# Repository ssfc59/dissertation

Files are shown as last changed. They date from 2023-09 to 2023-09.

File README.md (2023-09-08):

# Warm Reminders in Cool Spaces: Real-time monitoring of the thermal environment in Stratford Library with an integrated sensing and display device

## Overview





This "Warm Reminder" is a device that both senses and shows the real-time comparative temperature and humidity inside Stratford Library, a designated Tier 1 Cool Space by the Greater London Authority, and the surrounding area. It also sends the exact values recorded by the device over time to a data visualisation platform.

 As part of a collaboration with Newham Council and Stratford Library staff, this device was deployed in the library to inform both library staff and visitors of the facility's cooling efficacy and investigate its adherence to the 2023 Cool space criteria of having a "cooler indoor temperature than outdoors" during hot weather.

It aimed to engage both the public and the government on the emerging problem of heat, which could enourage heat adapation measures on both an individual and urban management level to increase community climate resilience to the adverse effects of extreme heat exposure.

To see the exact values recorded by this device, [click here](https://go.init.st/6woxrdn) or scan the QR code, and [click here to view the GLA Cool Spaces Map.](https://apps.london.gov.uk/cool-spaces/)

## Research Question
Can deploying a real-time integrated temperature and humidity sensing and display device inside Stratford Library help to indicate its cooling efficacy as a cool space over time?

## Device Function
The device takes the form of a large book-shaped light-up textual display that shows a comparative sentence of Stratford Library’s temperature and humidity values compared to outside on its “book cover”. 

It is run by a **FireBeetle ESP32 IOT Microcontroller**, which controls a **WS2812B LED strip** on the inside and a **DHT22 temperature and humidity sensor** on its side. 

Every 3 minutes from 9am-8pm, Stratford Library’s opening hours, the device collects and compares temperature, humidity, and heat index readings from the DHT22 sensor and the Met Office’s Weather DataHub, lights up the corresponding values and modifiers on the display, then sends the collected values to Initial State, a data visualisation platform that visualises the exact values of each variable over time on multiple charts.

## Device Fabrication
My device incorporates the visual features of a book, including its shape, material, proportion, and textual display format in its design as a reference to its placement in Stratford Library.

I used boxes.py, Fusion360, and Adobe Illustrator to make a laser cut template of a book shaped box with a curved side, with cut out stencilled text of the value displays onto its front, and cut it out of black acrylic. 




I then attached the LED strip to the back of each display row.



Lastly, I designed and laser cut a paper overlay with permanent parts of the sentence display and placed it on the device's front face to conceal the cutouts, only allowing the LED-lit values and descriptors to be visible.




I also laser cut 2 vertically lined pieces of white paper and placed them on the sides, making it resemble the pages of a book between book covers.



When the device is working, the display shows a sentence that compares the real-time temperature and humidity values inside Stratford Library to that outside. 



## Code Components
After connecting to WiFi successfully, my device’s code comprises 6 main chunks:

1.	Obtain the current hour and run the rest of the code if it is between 9am-8pm.

2.	Make a secured Get request to the Weather DataHub API to obtain the temperature, humidity, and “feels like” temperature of the area around Stratford Library.

3.	Obtain temperature, humidity, and heat index readings from the DHT22 sensor.

4.	Subtract the API values from the sensor values to find the temperature and humidity difference between Stratford Library and the surrounding outdoor area.

5.	Light up the LED lights to illuminate the corresponding numerical values and text descriptions on the display.

6.	Post all the received values to Initial State.

7.	2-minute delay between iterations.

### Arduino Libraries:

- [EzTime Library](https://github.com/ropg/ezTime) was used to obtain the current hour in a simple way.
- [ArduinoJson](https://arduinojson.org/) was used to deserialise the API response from Met Office DataHub.
- [WiFiClientSecure](https://github.com/espressif/arduino-esp32/blob/master/libraries/WiFiClientSecure/README.md) was used to make secure GET and POST requests.
- [FastLED](https://github.com/FastLED/FastLED) was used to control the LED lights.

## Repository contents
- Code
- Laser cut templates
- 3D printed ESP32 enclosure
- Data collected

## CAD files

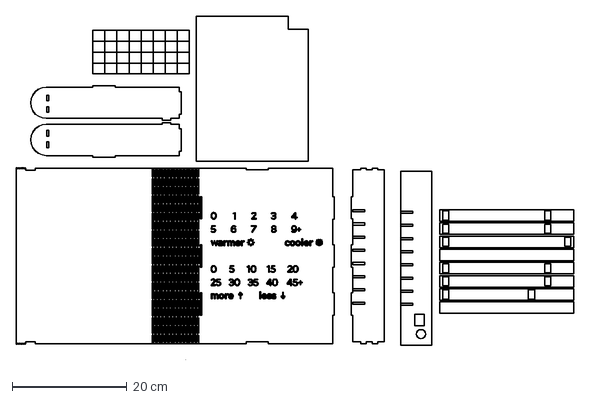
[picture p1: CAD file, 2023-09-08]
device-acrylic-laser-cut.dxf
97.3 x 60.0 cm

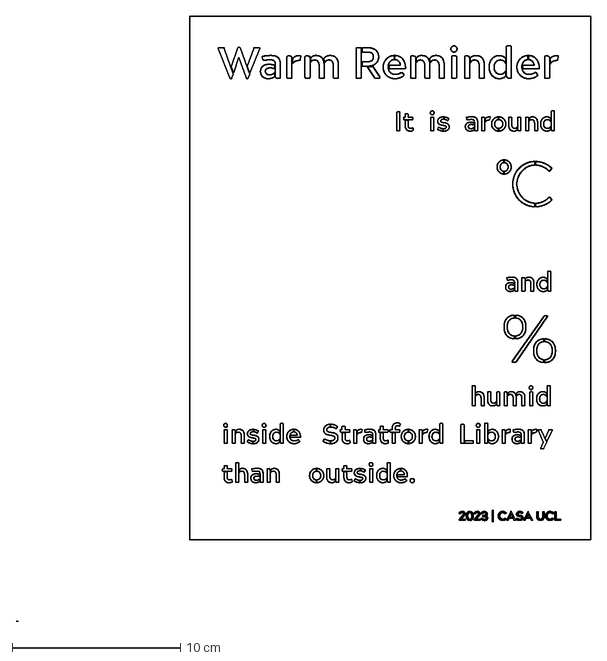
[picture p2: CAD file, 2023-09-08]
laser cut templates/device-front-paper-overlay.dxf
34.1 x 35.9 cm

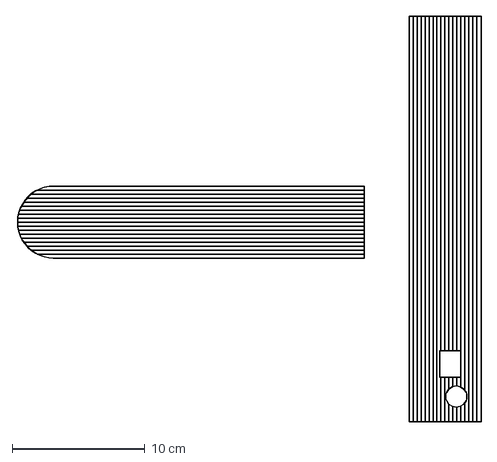
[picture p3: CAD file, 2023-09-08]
laser cut templates/device-sides-paper-overlay.dxf
35.1 x 30.6 cm

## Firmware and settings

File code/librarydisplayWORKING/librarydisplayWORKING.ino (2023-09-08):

#include <ArduinoJson.h>
#include <Arduino.h>
#include <WiFi.h>
#include <WiFiClientSecure.h>
#include <HTTPClient.h>

//ezTime library
#include <ezTime.h>
Timezone myTimezone;
int startHour = 8;    // Start hour (24-hour format)
int endHour = 20;

// LEDS
#include <FastLED.h>
#define NUM_LEDS 192     //Number of RGB LED beads
#define DATA_PIN D8    //The pin for controlling RGB LED
#define LED_TYPE WS2812B    //RGB LED strip type
CRGB leds[NUM_LEDS];    //Instantiate RGB LED

// DHT
#include "DHT.h"
#define DHTPIN D3    // Digital pin connected to the DHT sensor
#define DHTTYPE DHT22
DHT dht(DHTPIN, DHTTYPE);

//WiFi
int counter = 0;

#include "arduino_secrets.h";

void setup()
{
  // init serial
  Serial.begin(115200);

  //init LEDs
  FastLED.addLeds<LED_TYPE, DATA_PIN>(leds, NUM_LEDS);
  Serial.println();
  FastLED.clear();

  //init DHT
  dht.begin();
  Serial.println("wake device up for 5 seconds");
  delay(5000);

  //init WiFi
  WiFi.mode(WIFI_STA);
  WiFi.begin(ssid, password);
  Serial.print("Connecting to WiFi ..");
  while (WiFi.status() != WL_CONNECTED) {
    Serial.print('.');
//shows 1C cooler and 10% more humid
    for (int i = 183; i <= 186; i++) {
      leds[i] = CRGB (255, 255, 255);
      FastLED.show();
    }

    for (int i = 92; i <= 102; i++) {
      leds[i] = CRGB (255, 255, 255);
      FastLED.show();
    }

    //1 cooler
    //10 more

    for (int i = 1; i <= 10; i++) {
      leds[i] = CRGB (255, 255, 255);
      FastLED.show();
    }

    for (int i = 70; i <= 72; i++) {
      leds[i] = CRGB (255, 255, 255);
      FastLED.show();
    }

    counter++;
    delay(1000);
    if (counter >= 300) { //60 seconds timeout - reset board
      Serial.print(F("failed to connect after 60 seconds, reset board"));
      ESP.restart();
    }
  }
  FastLED.clear();
  counter = 0; //reset counter
  Serial.println(WiFi.localIP());
  waitForSync();
  myTimezone.setPosix("GMT0BST,M3.5.0/1,M10.5.0"); //set timezone to GMT
}

void loop () {
  /////////////////////
  // 1. Get the time //
  /////////////////////

  int currentHour = myTimezone.hour();
  Serial.println("Current Hour is ");
  Serial.print(currentHour);
  Serial.println(":00");

  /////////////////////////////////
  // 2. Make secured Get Request //
  /////////////////////////////////


  if (currentHour >= startHour && currentHour < endHour) {
    WiFiClientSecure *client = new WiFiClientSecure;
    // set secure client without certificate
    client->setInsecure();
    //create an HTTPClient instance
    HTTPClient https;
    https.begin(*client, APIurl);
    Serial.print("[HTTPS] GET...\n");
    https.addHeader("X-IBM-Client-Id", clientId);
    https.addHeader("X-IBM-Client-Secret", clientSecret);
    https.setTimeout(5000);
    int httpCode = https.GET();

    if (httpCode <= 0) {
      Serial.printf("[HTTPS] GET... failed, error: %s\n", https.errorToString(httpCode).c_str());
      Serial.println(F("Error on API request"));
      Serial.print(F("Restarting in 5 seconds..."));
      delay(5000);
      ESP.restart(); //restart ESP32
    }


    else {
      String payload = https.getString();

      //Parse response
      DynamicJsonDocument doc(49152);
      DeserializationError error = deserializeJson(doc, payload);

      // Test if parsing succeeds
      if (error) {
        Serial.print(F("deserializeJson() failed: "));
        Serial.println(error.f_str());
        return;
      }

      //fetch and store values
      float Temperature = doc["features"][0]["properties"]["timeSeries"][2]["screenTemperature"];
      float Humidity = doc["features"][0]["properties"]["timeSeries"][2]["screenRelativeHumidity"];
      float HeatIndex = doc["features"][0]["properties"]["timeSeries"][2]["feelsLikeTemperature"];

      //print values
      Serial.print(F("Outside temperature: "));
      Serial.print(Temperature);
      Serial.print(F(" | Outside humidity: "));
      Serial.print(Humidity);
      Serial.print(F(" | Ambient temperature: "));
      Serial.print(HeatIndex);
      Serial.println();

      //////////////////////////
      // 3. Obtain DHT values //
      //////////////////////////

      // Reading temperature, humidity and heat index
      float t = dht.readTemperature();
      float h = dht.readHumidity();
      float hic = dht.computeHeatIndex(t, h, false);
      //heat index = what the temperature feels like to the human body when relative humidity is combined with the air temperature.
      //false so it returns values in degrees Celsius

      // Check if any reads failed and exit early (to try again).
      if (isnan(h) || isnan(t) || isnan(hic)) {
        Serial.println(F("Failed to read from DHT sensor!"));
        Serial.println(F("2 minutes to debug..."));
        delay(120000);
        return;
      }

      Serial.print(F("Temperature: "));
      Serial.print(t);
      Serial.print(F("°C |"));
      Serial.print(F("Humidity: "));
      Serial.print(h);
      Serial.print(F("% |"));
      Serial.print(F(" Heat index: "));
      Serial.print(hic);
      Serial.print(F("°C "));
      Serial.println();

      //////////////////////////////////////
      // 4. Compare sensor and API values //
      //////////////////////////////////////

      int tempdisplay = t - Temperature;
      Serial.print(F("tempdisplay = "));
      Serial.print(tempdisplay);
      Serial.print(F("°C"));
      Serial.println();

      int humiditydisplay = h - Humidity;
      Serial.print(F("humiditydisplay = "));
      Serial.print(humiditydisplay);
      Serial.print(F("°C"));
      Serial.println();

      ////////////////////////////////////////////
      //  5. Light up corresponding LED lights  //
      ////////////////////////////////////////////

      FastLED.clear();
      if (tempdisplay <= 0) {
        //COOLER INSIDE THE LIBRARY
        for (int i = 92; i <= 102; i++) {
          leds[i] = CRGB (255, 255, 255);
          FastLED.show();
        }
      }
      else if (tempdisplay > 0) {
        //WARMER INSIDE THE LIBRARY
        for (int i = 109; i <= 120; i++) {
          leds[i] = CRGB (255, 255, 255);
          FastLED.show();
        }
      }
      switch (tempdisplay) {
        case 0:
          for (int i = 188; i <= 192; i++) {
            leds[i] = CRGB (255, 255, 255);
            FastLED.show();
          }
          break; //end case, light up 0

        case -1:
        case 1:
          for (int i = 183; i <= 186; i++) {
            leds[i] = CRGB (255, 255, 255);
            FastLED.show();
          }
          break; //end case, light up 1

        case -2:
        case 2:
          for (int i = 179; i <= 181; i++) {
            leds[i] = CRGB (255, 255, 255);
            FastLED.show();
          }
          break; //end case, light up 2

        case -3:
        case 3:
          for (int i = 174; i <= 176; i++) {
            leds[i] = CRGB (255, 255, 255);
            FastLED.show();
          }
          break; //end case, light up 3

        case -4:
        case 4:
          for (int i = 169; i <= 170; i++) {
            leds[i] = CRGB (255, 255, 255);
            FastLED.show();
          }
          break; //end case, light up 4

        case -5:
        case 5:
          for (int i = 128; i <= 132; i++) {
            leds[i] = CRGB (255, 255, 255);
            FastLED.show();
          }
          break; //end case, light up 5

        case -6:
        case 6:
          for (int i = 133; i <= 135; i++) {
            leds[i] = CRGB (255, 255, 255);
            FastLED.show();
          }
          break; //end case, light up 6

        case -7:
        case 7:
          for (int i = 138; i <= 140; i++) {
            leds[i] = CRGB (255, 255, 255);
            FastLED.show();
          }
          break; //end case, light up 7

        case -8:
        case 8:
          for (int i = 143; i <= 145; i++) {
            leds[i] = CRGB (255, 255, 255);
            FastLED.show();
          }
          break; //end case, light up 8

        case -50 ... -9:
        case 9 ... 50:
          for (int i = 148; i <= 151; i++) {
            leds[i] = CRGB (255, 255, 255);
            FastLED.show();
          }
          break; //end case, light up 9+

        default:
          for (int i = 0; i < NUM_LEDS; i++) {
            leds[i] = CRGB(100, 100, 0); //yellow
            FastLED.show();
          }
          Serial.print("Sensor error");
      }

      if (humiditydisplay <= 0) {
        //LESS HUMID
        for (int i = 13; i <= 19; i++) {
          leds[i] = CRGB (255, 255, 255);
          FastLED.show();
        }
      }
      else if (humiditydisplay > 0) {
        //MORE HUMID
        for (int i = 1; i <= 10; i++) {
          leds[i] = CRGB (255, 255, 255);
          FastLED.show();
        }
      }

      switch (humiditydisplay) {
        case -4 ... -1:
        case 0:
        case 1 ... 4:
          for (int i = 60; i <= 63; i++) {
            leds[i] = CRGB (255, 255, 255);
            FastLED.show();
          }
          break; //end case, light up 0

        case -9 ...-5:
        case 5 ... 9:
          for (int i = 65; i <= 67; i++) {
            leds[i] = CRGB (255, 255, 255);
            FastLED.show();
          }
          break; //end case, light up 5

        case -14 ...-10:
        case 10 ... 14:
          for (int i = 70; i <= 72; i++) {
            leds[i] = CRGB (255, 255, 255);
            FastLED.show();
          }
          break; //end case, light up 10

        case -19 ...-15:
        case 15 ... 19:
          for (int i = 75; i <= 77; i++) {
            leds[i] = CRGB (255, 255, 255);
            FastLED.show();
          }
          break; //end case, light up 15

        case -24 ...-20:
        case 20 ... 24:
          for (int i = 80; i <= 83; i++) {
            leds[i] = CRGB (255, 255, 255);
            FastLED.show();
          }
          break; //end case, light up 20

        case -29 ... -25:
        case 25 ... 29:
          for (int i = 52; i <= 54; i++) {
            leds[i] = CRGB (255, 255, 255);
            FastLED.show();
          }
          break; //end case, light up 25

        case -34 ... -30:
        case 30 ... 34:
          for (int i = 47; i <= 49; i++) {
            leds[i] = CRGB (255, 255, 255);
            FastLED.show();
          }
          break; //end case, light up 30

        case -39 ... -35:
        case 35 ... 39:
          for (int i = 42; i <= 45; i++) {
            leds[i] = CRGB (255, 255, 255);
            FastLED.show();
          }
          break; //end case, light up 35

        case -44 ... -40:
        case 40 ... 44:
          for (int i = 38; i <= 40; i++) {
            leds[i] = CRGB (255, 255, 255);
            FastLED.show();
          }
          break; //end case, light up 40

        case -100 ... -45:
        case 45 ... 100:
          for (int i = 30; i <= 35; i++) {
            leds[i] = CRGB (255, 255, 255);
            FastLED.show();
          }
          break; //end case, light up 45+

        default:
          for (int i = 0; i < NUM_LEDS; i++) {
            leds[i] = CRGB(100, 100, 0); //yellow
            FastLED.show();
          }
          Serial.print("Sensor error");
      } //switch humiditydisplay

      //////////////////////////////////////////
      //  6. send all values to Initial State //
      //////////////////////////////////////////

      String url = "https://groker.init.st/api/events?accessKey=";
      url += accesskey;
      url += "&bucketKey=";
      url += bucketkey;
      url += "&temperature=";
      url += t;
      url += "&humidity=";
      url += h;
      url += "&heatIndex=";
      url += hic;
      url += "&outsideTemp=";
      url += Temperature;
      url += "&outsideHumidity=";
      url += Humidity;
      url += "&outsideHeatIndex=";
      url += HeatIndex;
      url += "&tempDiff=";
      url += tempdisplay;
      url += "&humidityDiff=";
      url += humiditydisplay;


      //sent values to initial state via url
      Serial.print(F("requesting created URL: code "));
      https.begin(*client, url.c_str());

      https.setTimeout(5000);
      //Check for the returning code
      int serverhttpCode = https.GET();

      Serial.print(serverhttpCode);

      if (serverhttpCode > 0) {
        String payload = https.getString();
        Serial.println();
        Serial.println("values sent");
      }
      else {
        Serial.print( https.errorToString(serverhttpCode).c_str() );
        Serial.println("Error on HTTP request");
        Serial.println("Debug or refresh");
        Serial.print(F("Restarting in 5 seconds..."));
        delay(5000);
        ESP.restart(); //restart ESP32
      } //error else
      https.end(); //End
    } //big else
    /*end of sending to initial state*/
    Serial.println("request URL ended");
    Serial.println("HTTP request ended");
    Serial.println("waiting 5 min");
    // https.end();
    delay(300000);
    //delay for HTTPS request....
  } // if start hour=>, <end hour
  else {
    FastLED.clear(); //now library closing hours, do nothing until library opens again
  }
}

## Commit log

2023-06-29 change in LED test
2023-07-06 fastled clear and serverhttpcode error troubleshooting
    [librarydisplayWORKING.ino]
2023-07-06 added wificlientsecure client to initial state,
    hopefully it fixes the random -1 error on http request it gets like once every hour
    [librarydisplayWORKING.ino]
2023-07-18 if and switch cases for LED strip
2023-07-18 did switch case for all leds
2023-07-19 if and switch cases for led code
2023-07-19 leds clear haha
2023-07-20 reorganised switch cases in ascending order
2023-07-20 clear leds when there's a server error
    [librarydisplayWORKING.ino]
2023-07-31 added espreset, changed bucket
    espreset to reset device when connection is refused
    [librarydisplayWORKING.ino]
